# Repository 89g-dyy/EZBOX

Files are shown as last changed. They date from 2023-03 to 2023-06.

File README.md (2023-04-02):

# EZBOX
这是一个以HITBOX为参考进行优化的布局，比MIXBOX更适合键盘玩家进阶，适合连续玩游戏时长超过2小时的玩家；



控制板采用树莓派PICO，芯片为RP2040；
PCB的线路布局参考https://github.com/OpenStickCommunity/GP2040-CE，建议直接用该项目的固件；
PCB的TYPEC下需要飞两根导线到树莓派pico底部，D+ -> TP2,D- -> TP3；
PCB绘制软件为嘉立创easyEDA，嘉立创工程https://oshwhub.com/89_g/89gbox

制作方法：
1、按照rev?文件夹里的bom&tools备齐物料与工具
2、将rev?\dwg内的顶板与底板制作出来(面板对切割的精密度要求比较高，不建议制作)
3、将rev?\GerBer_XXX交给PCB生产厂商生产出来（推荐嘉立创），选择好自己喜欢的颜色，嘉立创生产可以选择指定位置客编，这样PCB更整洁
  或者也可以在https://lceda.cn/editor#id=f018a354f8e147a6b28c85ed92779d2d这个网址里直接下单
  步骤：
    1)找到：制造=>一键PCB/SMT下单
    2)继续下单后数据生成完毕点确定
    3)进入下单页面后登录，选择类型、
    4)材质选择FR-4;
      阻焊颜色选择白色;
      外观包装要求里的板上不加客编选择：指定位置加客编，选择不确定生产稿;
      SMT不需要；钢网不需要；
      发票建议电子个人发票；
      其他的默认即可；

4、按照RP2040文件夹里的readme刷好固件
5、制作过程中需要仔细阅读每一个文件夹下的readme.txt

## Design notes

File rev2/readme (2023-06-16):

dwg文件夹内是亚克力或者其他材质的切割文件
gerber是电路板文件，在嘉立创或者其他制造商生产
3dprint是3D打印的键帽文件，必须用这里的
厚度：1mm
客编：指定位置客编
不确认生产稿

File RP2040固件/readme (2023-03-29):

固件来源：https://github.com/OpenStickCommunity/GP2040-CE;

适用产品：
	树莓派pico、盗版树莓派pico(引脚一定要和正版一样);

使用方法：
	按住boot按钮再插usb，弹出硬盘后将GP2040-CE-RaspberryPiPico_v.0.5.2_Stick.uf2拖进去;

更多网页设置：
	断电后17脚(按下START)接地再插usb，接入后可松开;
	浏览器输入http://192.168.7.1/

其他设置：
http://192.168.7.1/settings

一、input mode（手柄模式）
	1、XInput：xbox360模式
	2、Nintendo Switch：任天堂ns pro手柄模式
	3、PS3/Direct：PS3手柄模式

二、D-pad Mode（左摇杆设置）
	1、D-pad：模拟十字键
	2、Left Analog：模拟左摇杆
	3、Right Analog：模拟右摇杆

三、SOCD Mode
	1、Up Priority：左右或上下同时触发时，保持先按下的键(推荐)
	2、Neutral：左右或上下同时触发时，互相抵消为中(默认)
	3、Last Win：左右或上下同时触发时，保持后按下的键(有些比赛禁止使用)

四、模式切换
	在插入摇杆时按住以下按钮开机将会切换模式，切换模式掉电也能保存
	1P - PS3/Dinput：适用于PS3/4主机模式
	1K - Nintendo Switch：适用于任天堂Switch
	2K - PC/XInput：适用于PC电脑或XBOX

       D-Pad模式
	切换D-Pad模式，在开机按以下按钮：
	SELECT + START + DOWN - 正常D-Pad模式
	SELECT + START + LEFT - 左模拟摇杆模式
	SELECT + START + RIGHT - 右模拟摇杆模式

       SOCD模式
	切换SOCD模式，可以实现一些后覆盖等特殊操作，在开机按以下按钮:
	HOME + START + DOWN - 回中 (U+D=N, L+R=N)
	HOME + START + UP - 方向上优先(U+D=U, L+R=N)
	HOME + START + LEFT - 最后输入优先(后覆盖)

       连发模式（V1.2新增）
	为1P/2P/3P/4P/1K/2K/3K/4K 8个按键增加了连发模式:
	连发模式每秒可以在 1 到 60 次之间进行调整（1次/秒-60次/秒）;
	如果连接了OLED，可以看到当前连发速度和已经连发的按钮;
	开启/关闭连发模式 - 按住TURBO(FN1)按钮和要设置连发的按钮;
	调整连发的速度 - 按住TURBO + UP 提高速度，按住TURBO + DOWN 降低速度;

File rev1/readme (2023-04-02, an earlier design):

DWG文件夹内是切割文件的图纸，可以直接交给亚克力或金属板材的商家进行切割；
Gerber是PCB制作文件，可以交给嘉立创或其他厂商打板（记得选择指定位置加客编）。
其中Gerber_1.2是没有typec转化电路的版本，制作比较简单，推荐新手使用这个版本，另外树莓派pico也有第三方的typec版本，只要引脚和官方版本一样就没有问题。

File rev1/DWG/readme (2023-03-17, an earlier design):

亚克力材料的情况下可以不做面板，因为亚克力的切割精度并没有那么高，面板可能对不上孔位，本人也没有去制作它;
底板和顶板在2.5mm厚的时候应该选M3*5平头螺丝，3.5mm后的时候则选择M3*6的平头螺丝;

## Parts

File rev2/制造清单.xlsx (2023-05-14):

名称 | 优先级 | 数量
顶板 | 必须 | 1
底板 | 必须 | 1
底盖板 | 推荐 | 1
18mm打印键帽(short) | 必须 | 7
20mm打印键帽(short) | 必须 | 8
22.5mm打印键帽(short) | 推荐 | 2
1gerber电路板(主体) | 必须 | 1
2gerber电路板(拓展) | 推荐 | 1
M3*5铜柱 | 必须 | 20
M3*5平头螺丝 | 必须 | 20
M3*4平头螺丝 | 必须 | 20
M3螺母 | 必须 | 20
2mm厚自粘硅胶贴 | 推荐 | 1
树莓派pico | 必须 | 1
0.96寸1603四针GND开头蓝色屏 | 推荐 | 1
此表格不包括工具，工具可参考rev1

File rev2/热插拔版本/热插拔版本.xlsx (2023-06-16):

名称 | 数量
面板(厚度=a) | 1
顶板 | 1
底板 | 1
底盖板 | 1
18mm打印键帽(short) | 7
20mm打印键帽(short) | 8
22.5mm打印键帽 | 2
电路板 | 1
M3*9铜柱 | 8
M3*(5+a)平头螺丝（固定面板） | 6
M3*7平头螺丝（固定电路板） | 5
M3*5平头螺丝（固定底板+盖板）
M3*5平头螺丝（固定顶板） | 2
M3螺母 | 5
2mm厚自粘硅胶贴 | 1
树莓派pico | 1
0.96寸屏 | 1
此表格不包括工具，工具可参考rev1

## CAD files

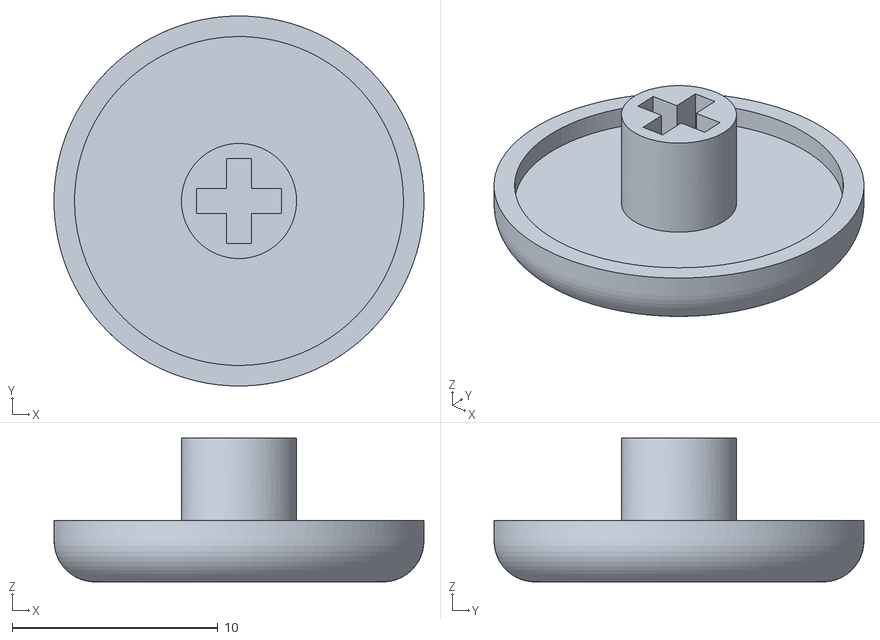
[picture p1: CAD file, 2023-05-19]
3D printing/rev2/18直径 8高度.stl
18.0 x 18.0 x 7.00

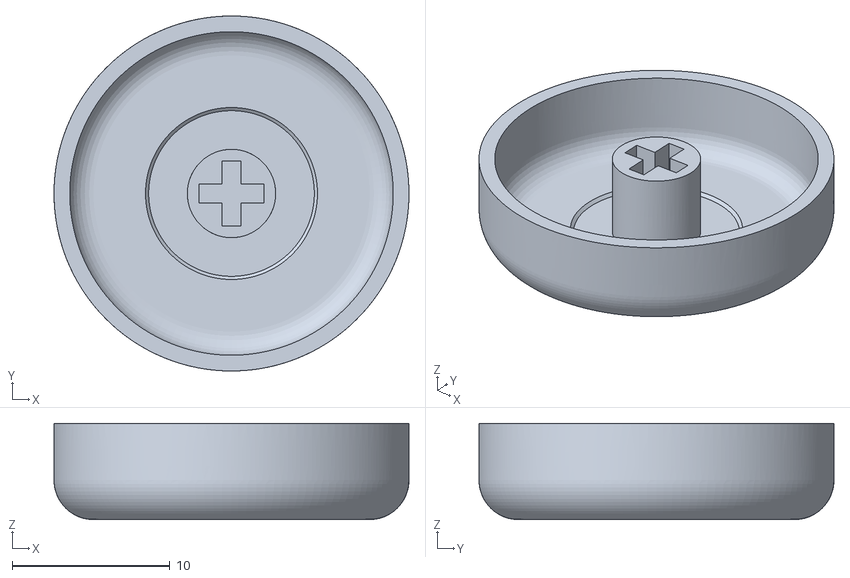
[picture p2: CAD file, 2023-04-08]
3D printing/taller/22.5.stl
22.5 x 22.5 x 6.10

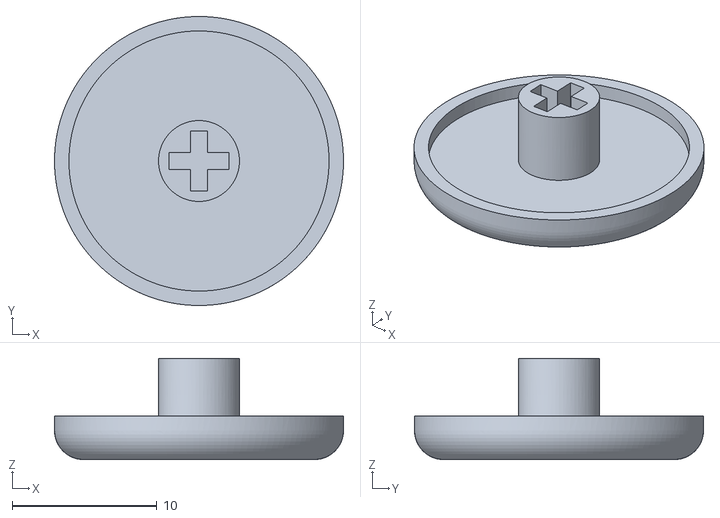
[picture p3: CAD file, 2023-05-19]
3D printing/rev2/20直径 8高度.stl
20.0 x 20.0 x 7.00

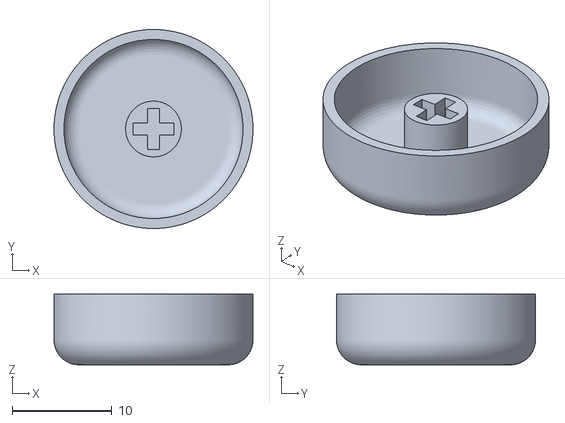
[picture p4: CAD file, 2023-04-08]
3D printing/taller/20.stl
20.0 x 20.0 x 7.10

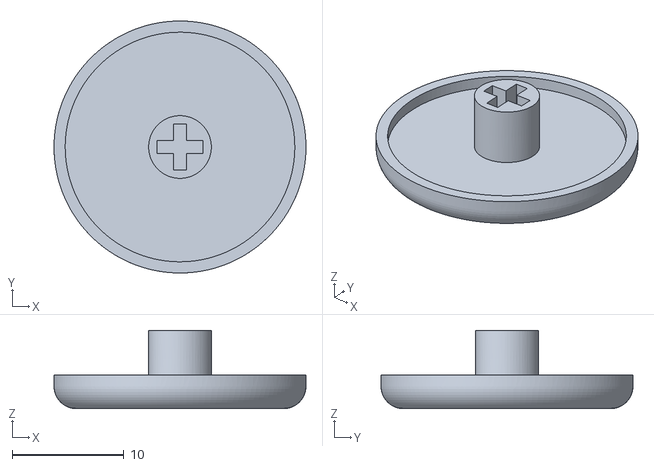
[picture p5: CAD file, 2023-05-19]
3D printing/rev2/22.5直径 8高度.stl
22.5 x 22.5 x 7.00

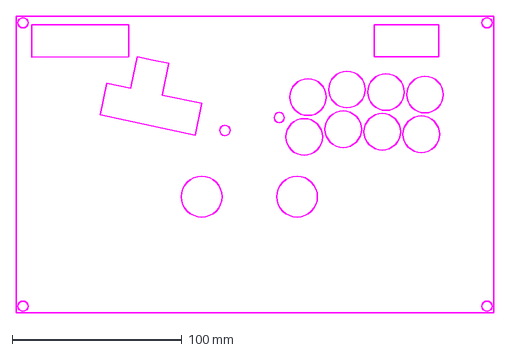
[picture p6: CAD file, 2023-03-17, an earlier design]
rev1/DWG/面板.dxf
281.6 x 175.0 mm

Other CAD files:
rev2/热插拔版本/亚克力/3mm底板.dwg
rev2/矮轴版本/亚克力/3mm底板.dwg
rev2/热插拔版本/亚克力/1-2mm面板.dwg
rev2/矮轴版本/亚克力/1-2mm面板.dwg
rev2/热插拔版本/亚克力/3mm顶板.dwg
rev2/矮轴版本/亚克力/3mm顶板.dwg
rev2/矮轴版本/亚克力/1mm底盖板.dwg
rev1/DWG/顶板2.5mm.dwg
rev1/DWG/底板2.5mm.dwg

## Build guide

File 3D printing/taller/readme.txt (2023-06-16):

This version fits the mixbox way
You need have the keycap like 'W' 'A' 'S' 'D'
20*8
22.5*2
